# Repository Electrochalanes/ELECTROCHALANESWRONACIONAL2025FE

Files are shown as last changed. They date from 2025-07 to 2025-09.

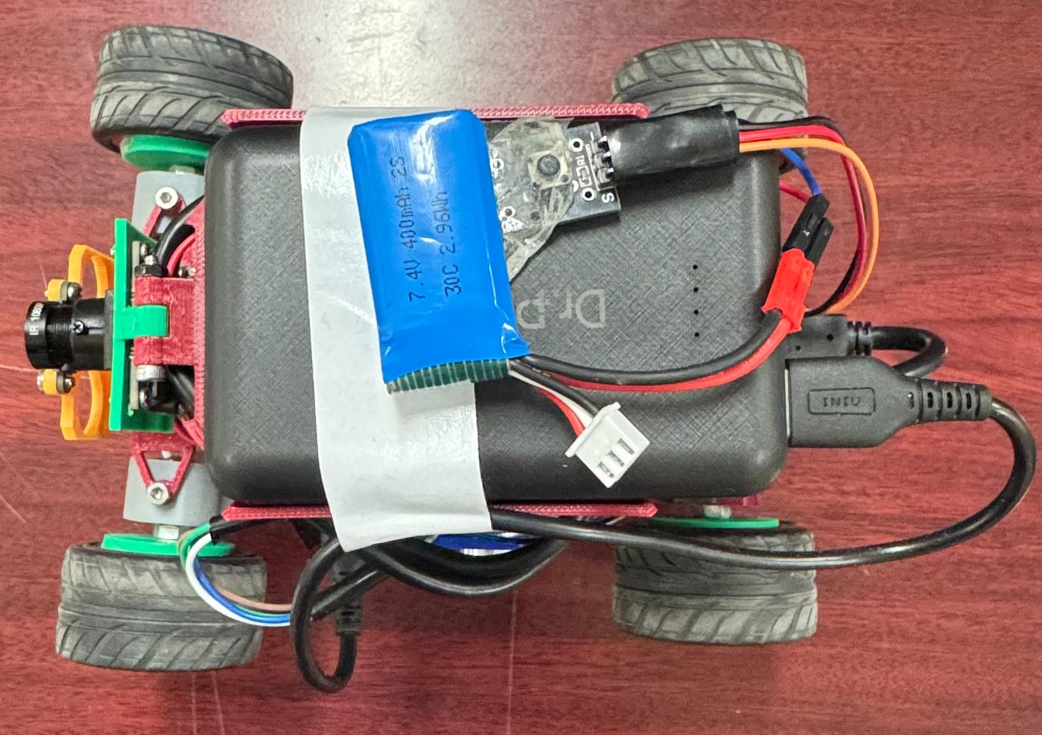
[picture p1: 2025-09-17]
v-photos/WRO ARRIBA.jpg

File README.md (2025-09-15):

Material de Ingeniería 
====

Este repositorio contiene el material que se utilizará para el nacional WRO Future Engineers Baja California 2025 y para una posibe participación en la etapa internacional. La explicación de cada uno de los apartados se encuentra en su sección correspondiente.

## Contenido

* `t-photos` Contiene 2 fotos del equipo (una oficial y otra con una pose divertida)
* `v-photos` Contiene 6 fotos del equipo (desde todas las perspectivas)
* `video` Contiene un archivo video.md con el enlace a Youtube para la demostración de movimiento y conducción.
* `schemes` Contiene uno o más archivos JPEG, PNG or PDF de los componentes electromecánicos (motores y componentes electrónicos) usados en el vehículo y como conectarlos.
* `src` Contiene los códigos utilizados para que el auto se conduzca en las 2 diferentes categorías de la competencia.
* `models` Contiene archivos para impresoras 3D, máquinas de corte láser para fabricar los elementos del vehículo.

## Introducción

"Chiquilín" como nos gusta llamarle a nuestro robot, es un vehículo diseñado y desarrollado por nosotros totalmente desde 0. El material utilizado para su creación es muy diverso y se obtuvo de varias fuentes, a continuación podrán observar una lista de este mismo: 

* Filamento PLA para impresora 3D
* Tablas de madera MDF
* Raspberry pi 5 16gb
* Powerbank 3000mAh
* Baterías lipo 7.4V (el amperaje va desde 400mAh)
* Motorshield SB components para raspberry pi
* Micromotoreductor Pololu HPCB 6V 50:1 
* 2 sensores ultrasónicos HC-SR04
* Sensor VL53L0X
* Servomotor con torque de 10 kgf/cm
* Tornillos y tuercas M5 hexagonales
* Módulo de cámara USB
* Pulsador pull down
* Vara de aluminio
* Jumpers, cable y alambre de calibre 22
* Bracket para micromotoreductor Pololu

## Objetivos el Robot:

# En el desafío abierto:
* Dar 3 vueltas a la pista y terminar en la sección de arranque

# Complicaciones: 
* Tiempo limitado
* Secciones pequeñas

# En el desafío de obstáculos:
* Detectar obstáculos
* Esquivar obstáculos
* Hacer lo anterior mientras conduce
* Estacionarse en la zona delimitado

# Complicaciones:
* Tiempo limitado
* Reducción del espacio debido a los obstáculos
* Ajustes de iluminación
* Ajustes de velocidad
* Rutina de estacionamiento

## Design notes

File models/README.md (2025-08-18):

En este directorio se encuentran todas las piezas diseñadas y modeladas en 3D, piezas para cortar en láser y un archivo que se cortó en aluminio (bara direccional.stl) que utilizamos para el armado del auto.

Nuestro robot
===

Nuestro automóvil es un robot cuya base y chasis fue diseñado totalmente desde cero. El robot se compone por más de 10 piezas fundamentales para su armado, desde las bases para cada uno de los componentes, hasta los diferentes pisos y mecanismos como lo es el direccional y la transmisión trasera para el motor y las llantas de esa zona. La distribució de cada uno de los elementos esta hecha para que los sensores abarquen el mejor ángulo posible y puedan brindar la mejor información a nuestra Raspberry Pi 5, la cual se ubica en el segundo piso. La base para la cámara se diseño en 3D para que fuera posible ajustarla según nuestra necesidades. Todos los diseños incluidos fueron utilizados en el proceso de armado del vehículo autónomo, así como un pequeño modelo de como se puede llegar a ver el robot ya armado

Se tomo la decisión de crear el carro de esta forma en base a nuestra experiencia en la competencia regional, donde aprendimos de nuestros errores anteriores y notamos las siguientes problemáticas:

* El robot era demasiado grande, lo cual dificultaba el maniobraje de este mismo.
* El diseño tenía una pésima distribución del peso lo que ameritaba fallas en zonas vulnerables, esto ocasionaba que se cayeran algunas piezas o que el carro fuera muy fácil de romperse.
* La vara direccional era muy propensa a debilitarse o doblarse con el estrés de las pruebas.
* Las piezas no estaban puestas de forma correcta y los componentes se desconectaban de forma constante.

Para resolver las dificultades anteriormente mencionadas se tomaron varias decisiones para el resultado que estamos presentando, las decisiones fueron:

* Hacer bases más pequeñas, agregar más pisos y reducir el tamaño de las llantas, transmisión y sistema direccional, todo esto para reducir significativamente el tamaño del automóvil.
* Reforzar el material y planificar una distribución del peso más idónea para la durabilidad de nuestro robot.
* Fabricar una vara direccional con aluminio, esto benefició enormemente a nuestro proyeco gracias a la reducción en el desgaste de esta misma, se pudo evitar el tener que cambiarla constantemente y ahorrarnos tiempo de armado.
* Organizar el cableado y mejorar las soldaduras utilizadas para evitar fallos por desconexiones o rompimiento de cables.

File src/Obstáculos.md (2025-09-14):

Configuración para el desafío de obstáculos
===

## Configuración del hardware:

```
import cv2
import numpy as np
from gpiozero import Motor, AngularServo, Button
from time import sleep
import board
import busio
from adafruit_vl53l0x import VL53L0X

# Hardware configuration
servo = AngularServo(18, min_angle=-90, max_angle=90,
                     min_pulse_width=0.5/1000, max_pulse_width=2.5/1000)
motor = Motor(forward=11, backward=9)
i2c = busio.I2C(board.SCL, board.SDA)
vl53 = VL53L0X(i2c)
boton = Button(12)
```
Explicación: Se importan las librerías necesarias y se configuran los componentes:

* Servomotor (GPIO 18): Controla la dirección del vehículo

* Motor (GPIO 11 y 9): Controla el movimiento hacia adelante/atrás

* Sensor VL53L0X: Sensor de distancia por láser

* Botón (GPIO 12): Da inicio al código

## Configuración de la cámara

```
cap = cv2.VideoCapture(0)
cap.set(cv2.CAP_PROP_FRAME_WIDTH, 640)
cap.set(cv2.CAP_PROP_FRAME_HEIGHT, 480)
```
 Configura la cámara con resolución 640x480 píxeles para el procesamiento de imágenes.

## DETECCIÓN DE COLORES

```
COLOR1_LOWER = np.array([67, 140, 88])  # Green
COLOR1_UPPER = np.array([179, 255, 255])

COLOR2_LOWER = np.array([158, 120, 40])  # Red (low range)
COLOR2_UPPER = np.array([175, 209, 71])
COLOR2B_LOWER = np.array([170, 100, 100])  # Red (high range)
COLOR2B_UPPER = np.array([179, 255, 255])
```
 Define los rangos HSV para detectar:

* Verde: Objetos a esquivar maniobrando a la izquierda

* Rojo: Objetos a esquivar maniobrando a la derecha

El rojo tiene dos rangos porque en la escala HSV el rojo aparece en ambos extremos del espectro

## PARÁMETROS DE NAVEGACIÓN

```
GREEN_EVASION_DISTANCE = 22  # 22cm
RED_EVASION_DISTANCE = 22  # 22cm
OBSTACLE_DISTANCE = 23  # 40cm
PARKING_DISTANCE = 6
```
Distancias en centímetros para:

* Evadir verde/rojo: 22cm

* Detectar obstáculos: 23cm

* Detectar estacionamiento: 6cm

## Máscara rectangular de la cámara

```
def apply_rectangular_mask(frame, rect_width, rect_height, y_offset):
```
Limita la visión a un área rectangular en la parte inferior de la imagen, enfocándose en lo que está frente al vehículo. Con esto se evita que el auto detecte frecuencias más allá de la zona de juego.

## SECUENCIAS DE MOVIMIENTO
```
Secuencia Inicial
def execute_initial_sequence():

Secuencia de Evasión
def evade_green():  # Gira a izquierda
def evade_red():    # Gira a derecha  
def avoid_obstacle(): # Evasión estándar

Secuencia de Estacionamiento
def execute_parking_sequence():
```

## Bucle Principal
```
while True:
    ret, frame = cap.read()
    distancia = read_constrained_distance_cm()
```
  ## Prioridad de Detección
```
  if color1_obj is not None:  # Verde - prioridad máxima
if color2_obj is not None:  # Rojo - prioridad media  
if color3_obj is not None:  # Estacionamiento - prioridad baja
```
## Lógica de Decisión
```
if distancia <= GREEN_EVASION_DISTANCE and objeto_detectado:
    evade_green()
elif distancia <= RED_EVASION_DISTANCE and objeto_detectado2:
    evade_red()
elif distancia > OBSTACLE_DISTANCE:
    motor.forward(0.25)  # Avanzar
elif distancia < OBSTACLE_DISTANCE:
    avoid_obstacle()  # Esquivar
    ```

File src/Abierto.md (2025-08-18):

Código para el Desafío Abierto
===

## Modos de Operación
El robot tiene tres modos configurables que se encuentran dentro de una matriz que decide las configuraciones según el modo:

```
config_modos = {
    'inner': {  # Para distancias cercanas
        'velocidad_giro': 0.35,
        'velocidad_recto': 0.3,
        'tiempo_giro': 1.8,
        'rango_setpoint': (60, 80),
        'condicion_sensor': (160, 100),
        'pid': {'Kp': 2.5, 'Ki': 0, 'Kd': 9.5},
        'sleep': 0
    },
    'middle': {  # Para distancias medias
        'velocidad_giro': 0.4,
        'velocidad_recto': 0.4,
        'tiempo_giro': 1.8,
        'rango_setpoint': (35, 60),
        'condicion_sensor': (80, 80),
        'pid': {'Kp': 3, 'Ki': 0, 'Kd': 8},
        'sleep': 0.5
    },
    'outter': {  # Para distancias lejanas
        'velocidad_giro': 0.35,
        'velocidad_recto': 0.4,
        'tiempo_giro': 1.4,
        'rango_setpoint': (0, 25),
        'condicion_sensor': (50, 80),
        'pid': {'Kp': 5.0, 'Ki': 0.35, 'Kd': 3.2},
        'sleep': 0.5
    }
}
```

Cada modo tiene parámetros específicos para:

* Velocidades en recto y giro
* Tiempos de giro
* Rangos de distancia objetivo (setpoint)
* Condiciones de sensor para detectar esquinas
* Constantes PID
* Tiempos de espera

### Inicio con botón
```
boton_inicio.wait_for_press()
SETPOINT = sensor.distance * 100  # Distancia inicial en cm
SETPOINT2 = sensor2.distance * 100
```
el robot espera la señal del botón y después establece la distancia inicial como referencia.

### Bucle principal (se detiene al ejecutarse 12 veces):
```
while turn_count < max_turns:
    distancia = sensor2.distance * 100
    distancia2 = sensor3.distance * 100
    
    # Selección de modo basado en SETPOINT
    for modo, config in config_modos.items():
        min_sp, max_sp = config['rango_setpoint']
        if min_sp <= SETPOINT <= max_sp:
            mfo = ejecutar_modo(modo)
            break
```

### Función ejecutar_modo()
Esta función indica cuando debe girar el carro, ajusta los parámetros de PID y se encarga de la condición de finalización.
```
def ejecutar_modo(modo):
    global turn_count, Kp, Ki, Kd
    config = config_modos[modo]
    
    if distancia <= distancia_max and distancia2 > distancia2_min:
        # Realizar giro
        motor.forward(config['velocidad_giro'])
        servo.angle = 31  # Ángulo para girar
        time.sleep(config['tiempo_giro'])
        servo.angle = 80.5  # Volver a posición central
        motor.forward(config['velocidad_recto'])
        time.sleep(config['sleep'])
        turn_count += 1  # Incrementar contador de segmentos
        
        if turn_count == max_turns:
            # Comportamiento final
            if distancia < SETPOINT2:
                motor.forward(0.4)
            else:
                motor.stop()
    
    # Actualizar parámetros PID
    Kp = config['pid']['Kp']
    Ki = config['pid']['Ki']
    Kd = config['pid']['Kd']
    
    return config['velocidad_recto']
```
### PID
Esta función ajusta el ángulo del servomotor para mantener al robot en la distancia indicada
```
# Calcular error
error = SETPOINT - distance

# Términos PID
P = Kp * error  # Proporcional
integral += error * elapsed
I = Ki * integral  # Integral
derivative = (error - previous_error) / elapsed
D = Kd * derivative  # Derivativo

pid_output = P + I + D

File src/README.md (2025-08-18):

Software del vehículo
====

En este directorio se encuentran los 2 códigos así como sus diagramas de flujo utilizados para el desafío abierto y el desafío de obstáculos, cabe recalcar que ambos se desarrollaron en base al lenguaje de programación Python en su versión más reciente y utilizando el IDE "Pycharm Comunnity Edition". La explicación detallada de los software estarán en archivos .md separados.

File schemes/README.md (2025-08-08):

Diagramas Electromecánicos
====

Este directorio contiene diagramas simples que ayudarán a entender como se conectan los componentes electrónicos para el armado del automóvil.

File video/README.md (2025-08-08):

Video
====

Este directorio contiene un enlace que lleva a un video publicado en Youtube en el que se demuestra el comportamento y conducción del vehículo en los diversos desafíos.

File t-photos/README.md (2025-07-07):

Fotos del equipo
====

En este directorio encontrarás 2 fotos de nuestro equipo.

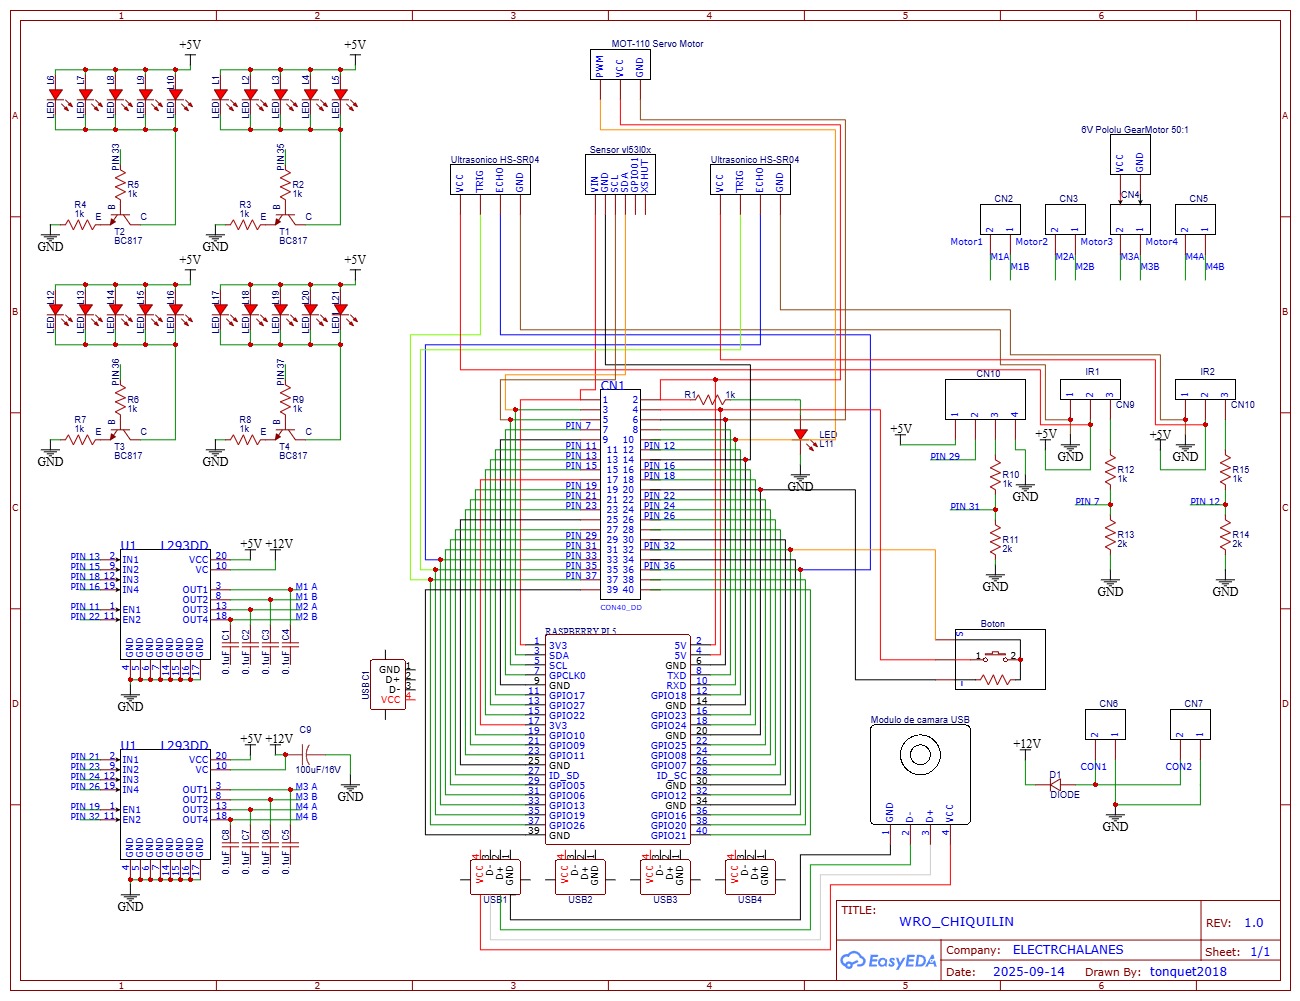
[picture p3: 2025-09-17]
schemes/DIAGRAMA2.jpg

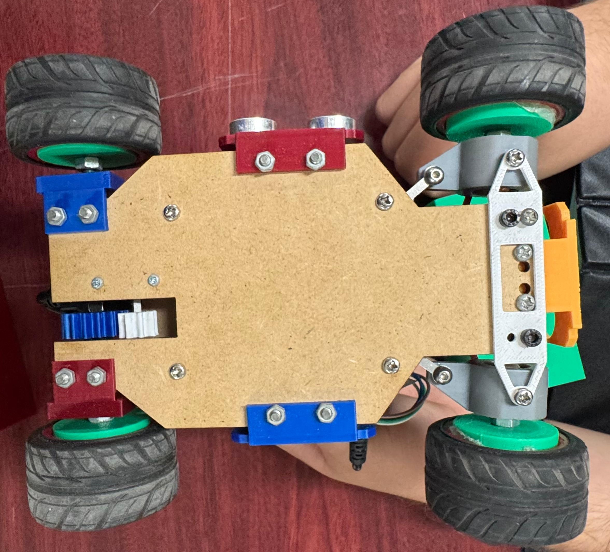
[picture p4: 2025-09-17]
v-photos/WRO ABAJO.jpg

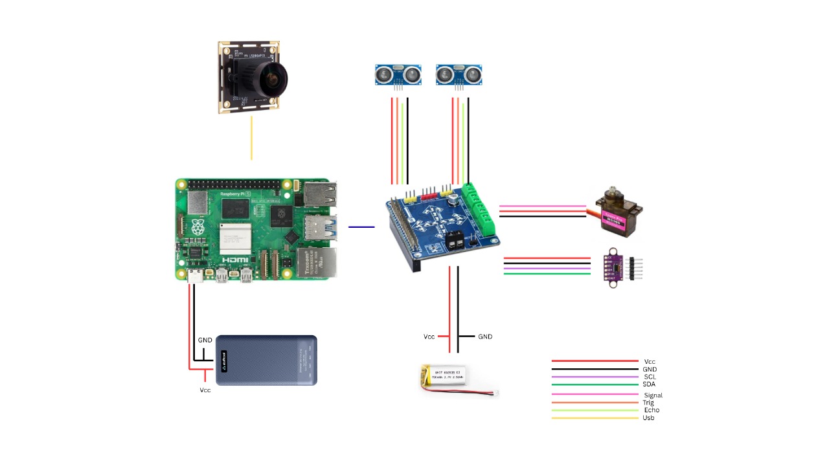
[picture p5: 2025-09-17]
schemes/DIAGRAMA1.jpg

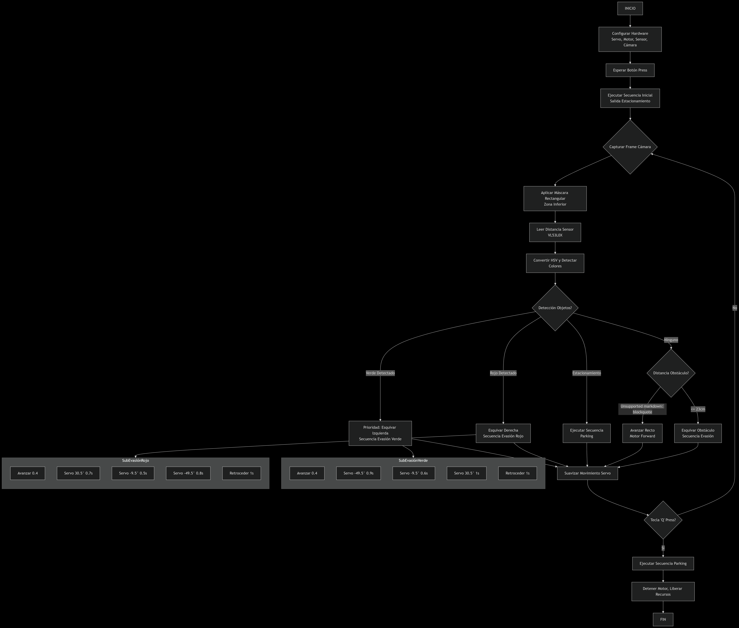
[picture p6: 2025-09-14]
src/Diagrama de flujo DO.png

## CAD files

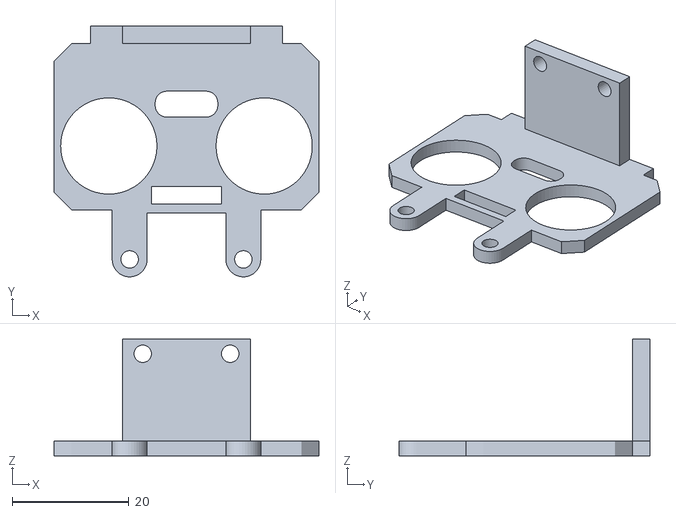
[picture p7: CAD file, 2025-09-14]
models/EYE vl53 v3.stl
45.5 x 43.0 x 20.0

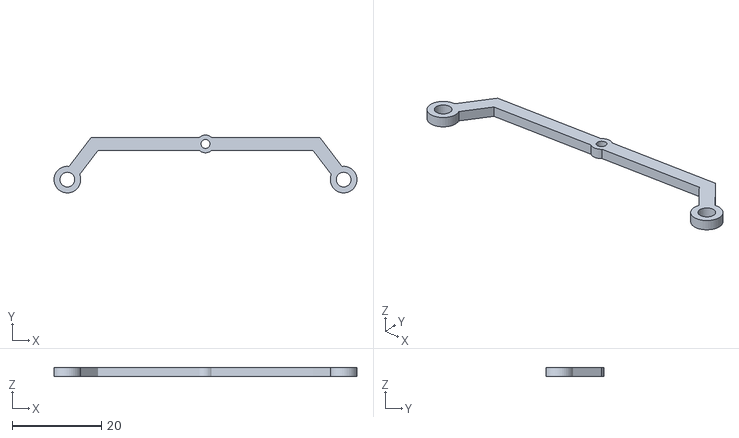
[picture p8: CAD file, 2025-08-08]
models/bara direccional.stl
68.0 x 13.0 x 2.00

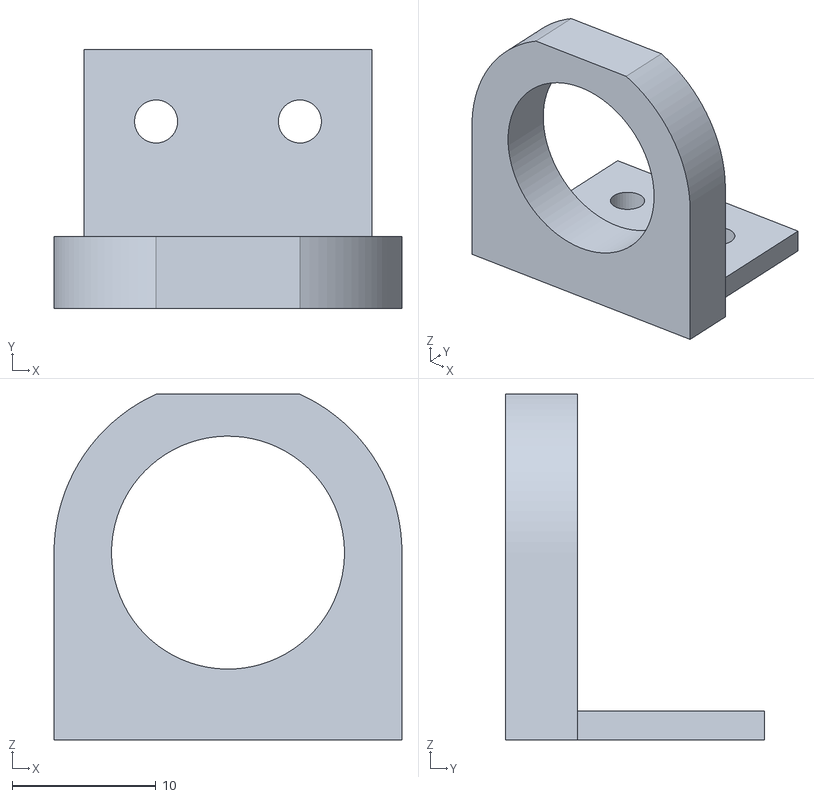
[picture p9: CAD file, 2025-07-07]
models/soten de balero trasero v3.stl
24.2 x 18.0 x 24.0

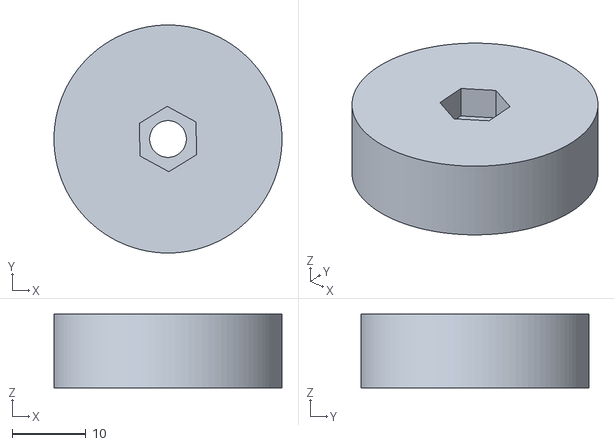
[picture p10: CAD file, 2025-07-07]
models/adaptador para llanta v2.stl
31.0 x 31.0 x 10.0

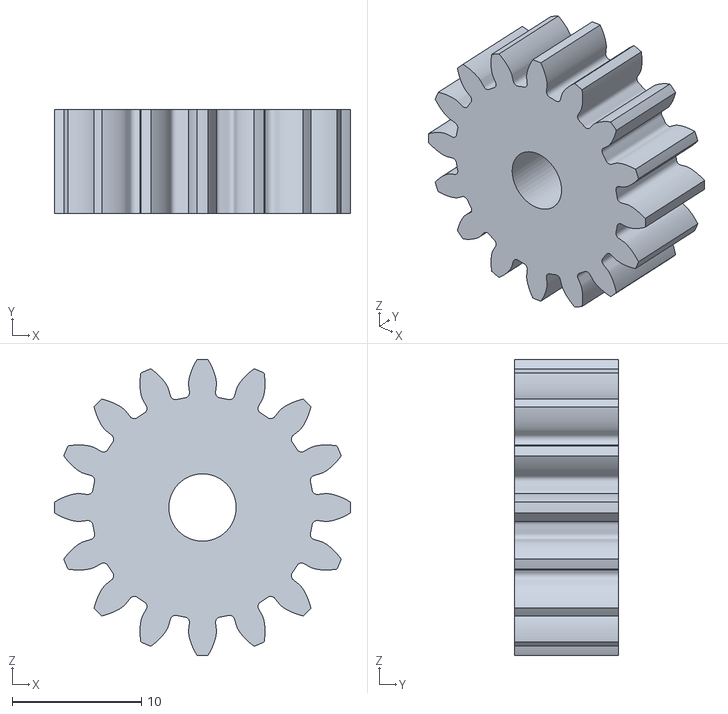
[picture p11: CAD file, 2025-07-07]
models/gear 5mm v3.stl
22.9 x 8.00 x 22.9

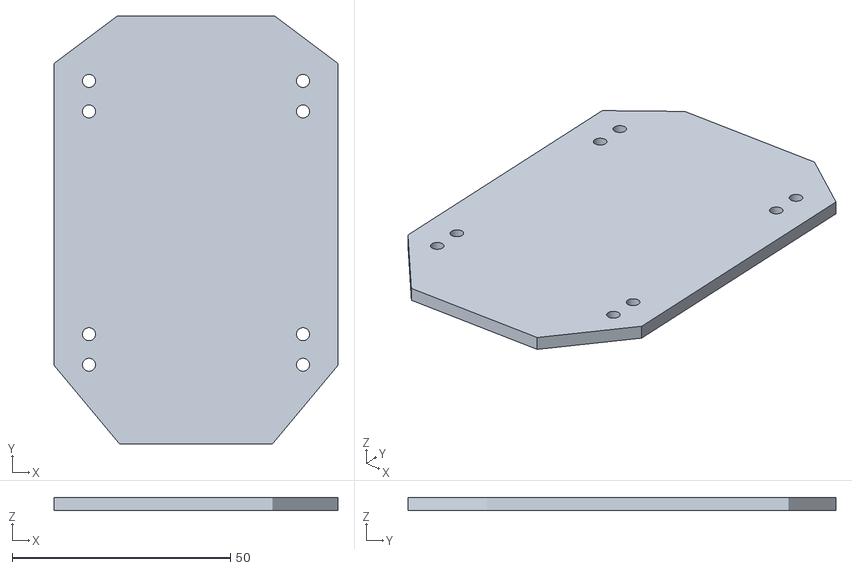
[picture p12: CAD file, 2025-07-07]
models/piso 2 v6.stl
65.0 x 98.0 x 3.00

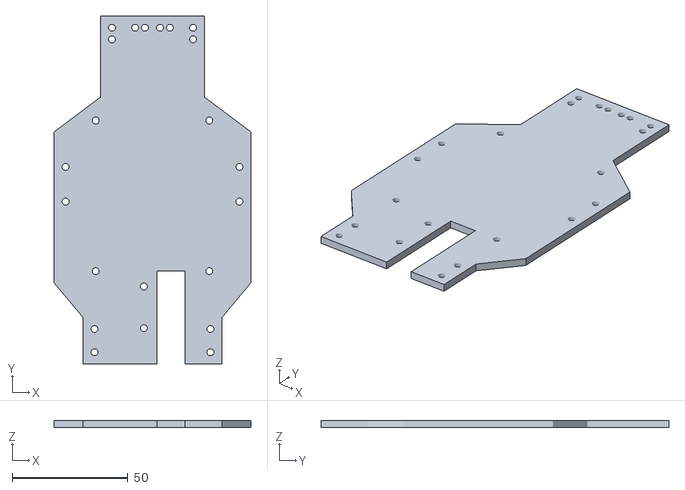
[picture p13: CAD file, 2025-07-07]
models/base wro nacional v21.stl
85.0 x 150.0 x 3.00

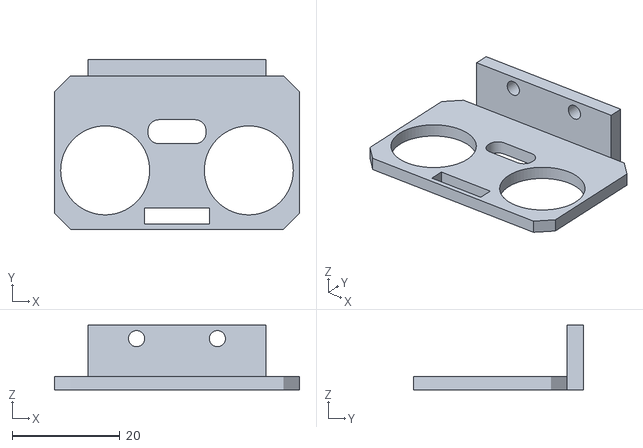
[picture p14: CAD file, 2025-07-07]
models/EYE v2 v6.stl
45.5 x 31.5 x 12.0

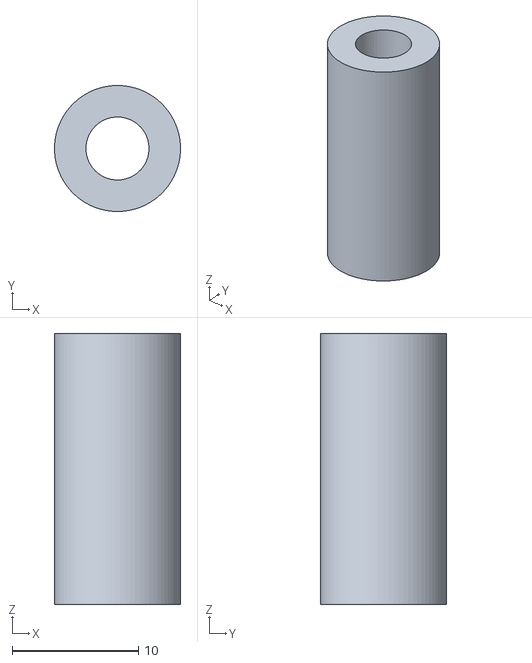
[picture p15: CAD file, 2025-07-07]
models/espaciador 1 v3.stl
10.0 x 9.99 x 21.5

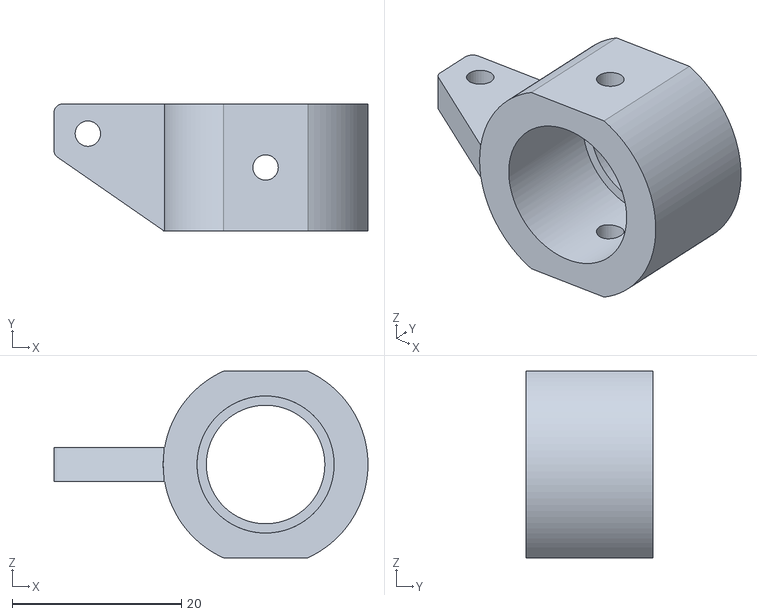
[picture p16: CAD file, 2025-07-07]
models/steer v1.stl
37.1 x 15.0 x 22.0

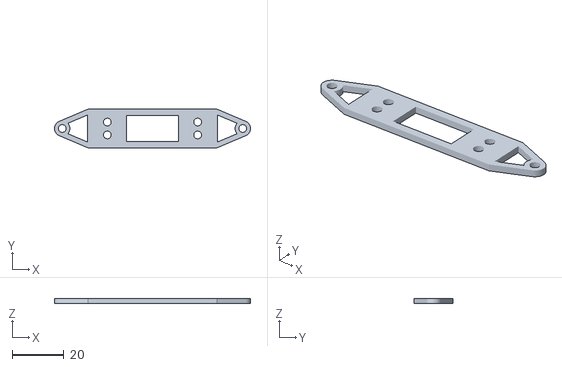
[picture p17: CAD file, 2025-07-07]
models/base de sistema steer v1.stl
76.0 x 15.0 x 2.00

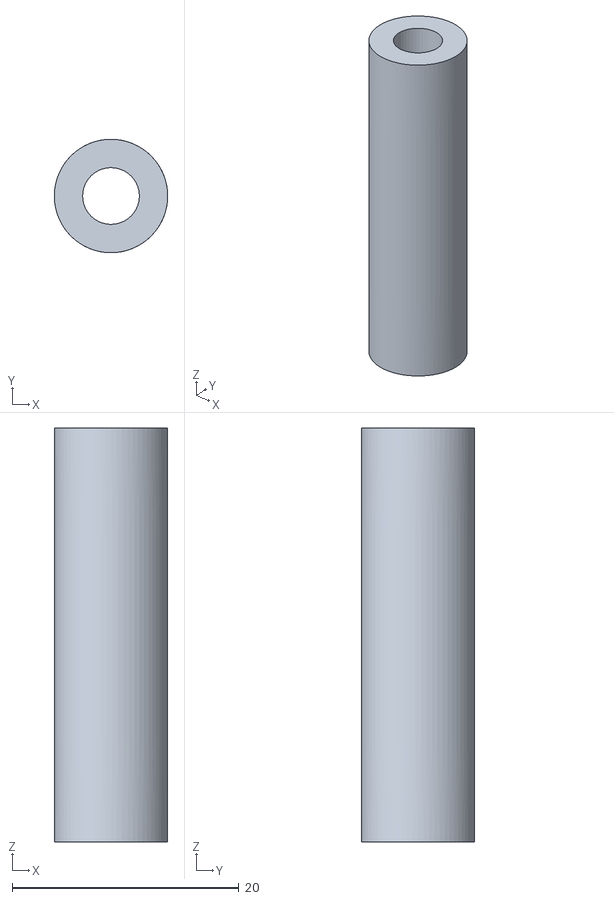
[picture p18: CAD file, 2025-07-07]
models/espaciador 2 v4.stl
10.0 x 10.0 x 36.5

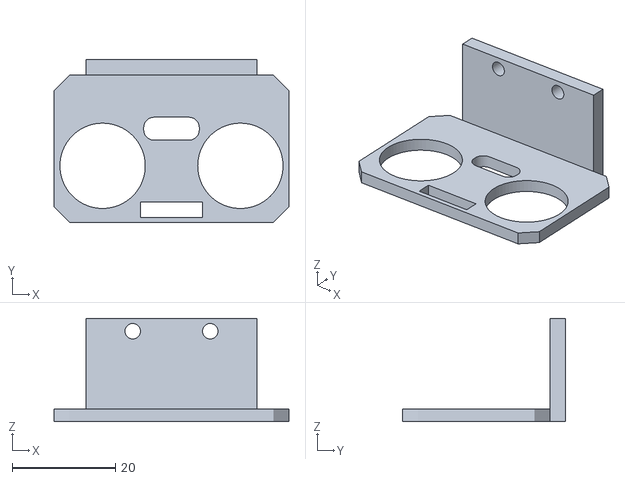
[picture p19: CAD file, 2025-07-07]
models/EYE FRONT v2.stl
45.5 x 31.5 x 20.0

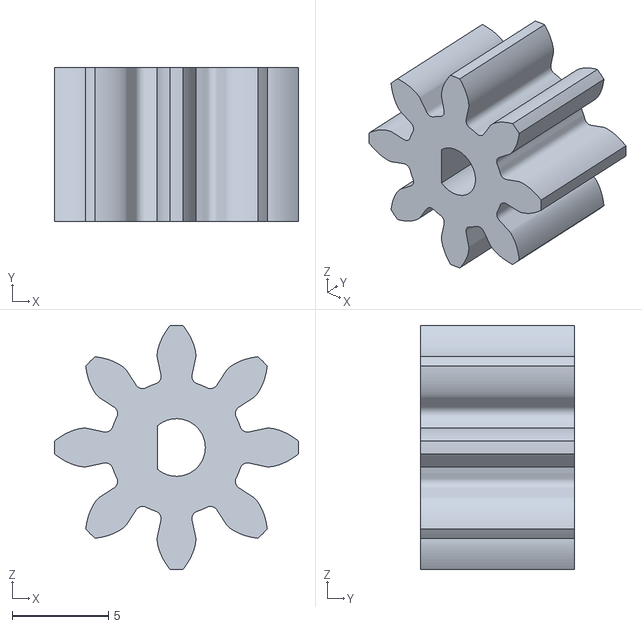
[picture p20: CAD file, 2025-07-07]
models/gear 34 v1.stl
12.7 x 8.00 x 12.7

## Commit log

2025-07-07 Add files via upload
    NOTA: "piso 2 v6" también se utilizó para el tercer piso.
    [EYE FRONT v2.stl, EYE v2 v6.stl, adaptador para llanta v2.stl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]
2025-07-07 Update README.md
    Primera versión del archivo principal de texto
